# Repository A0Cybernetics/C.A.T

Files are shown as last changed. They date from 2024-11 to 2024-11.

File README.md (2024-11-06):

# A0 Cybernetics: C.A.T
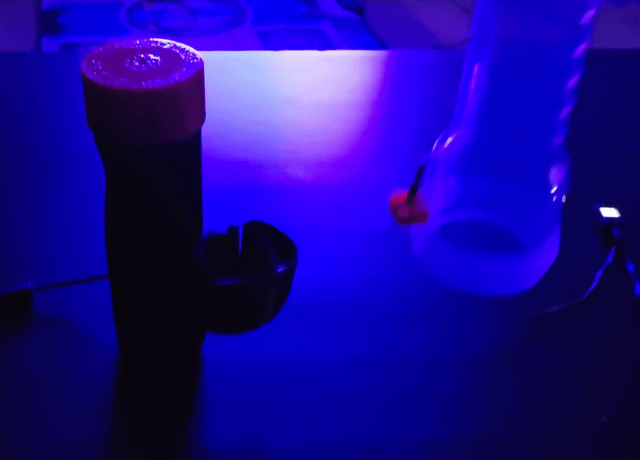
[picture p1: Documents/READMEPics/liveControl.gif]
liveControl
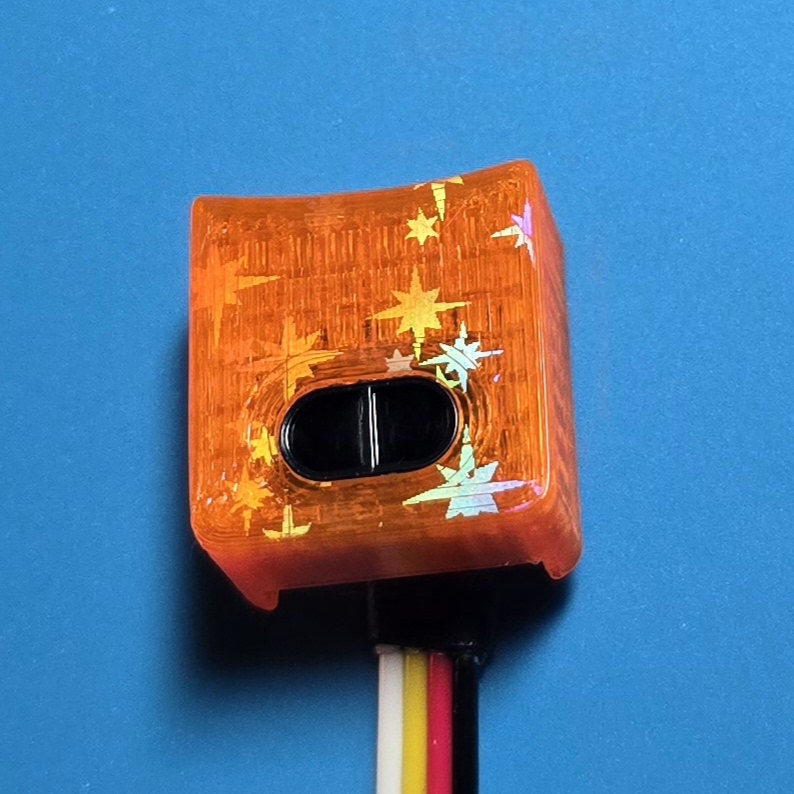
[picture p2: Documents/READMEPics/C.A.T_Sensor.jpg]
C.A.T_Sensor


An interactive adult entertainment device. It measures a targets distance from the sensor to control connected devices and interact with media.

- Free and open source. I do this because I like it <3

- Onboard TFT screen with customizable UI

- Control any computer UI slider based on the distance of a target from the sensor.

- Control most devices by using apps with sliders like Intiface Central, XToys, etc.

- Usable by any person.  Mount it on things with nano tape.  Point it at a target that moves farther and closer to the sensor.

- Read the [Build Guide](Documents/buildGuide.txt) for a parts list and fully detailed step-by-step instructions.

## License

[MIT](https://choosealicense.com/licenses/mit/)

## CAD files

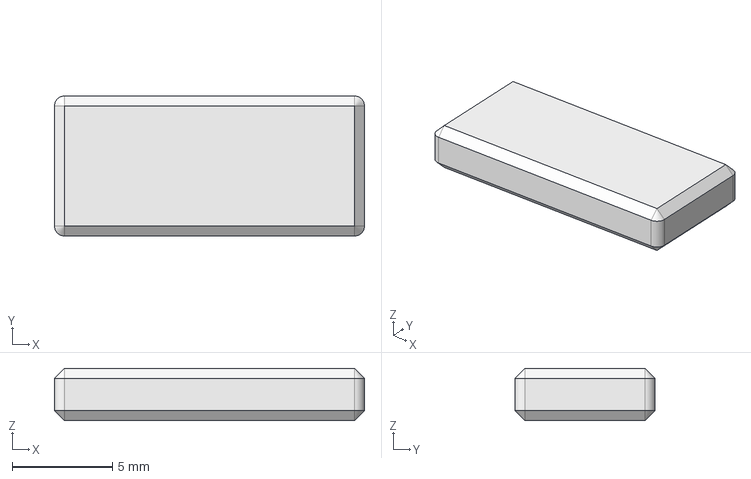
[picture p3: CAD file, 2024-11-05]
3DModels/C.A.T_Backplate-V1.0.FCStd
15.5 x 7.00 x 2.60 mm

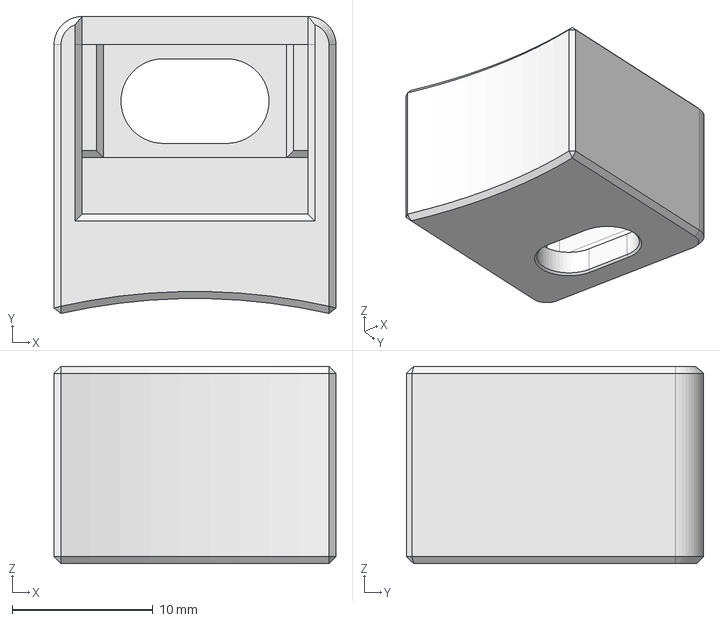
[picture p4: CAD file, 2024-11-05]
3DModels/C.A.T_Faceplate-V1.0.FCStd
20.0 x 21.1 x 14.0 mm

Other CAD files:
3DModels/C.A.T_Backplate-V1.0.stl
3DModels/C.A.T_Faceplate-V1.0.stl

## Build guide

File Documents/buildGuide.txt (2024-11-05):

---- C.A.T Build Guide ----
	*The pictures are in the C.A.T_InstructionPictures folder.

---- Parts List

1. LILYGO T-QT PRO (ESP32 S3FN8 VERSION) AND SHELL - Buy the shell to help protect the board, the pin and soldering options are your choice.
	https://www.lilygo.cc/products/t-qt-pro?variant=42568397324469

2. VL53L1X SENSOR BREAKOUT BOARD WITH COVER GLASS. One that looks like this picture (pic VL53L1X).  You can find them on Amazon, AliExpress, etc. for around $5.

3. Grove or QWIIC Cable - I recommend a long Grove Cable.  I have tested cabled up to 2 meters. 
	- The T-QT has a QWIIC Connector so you will need a Grove to QWIIC hub or another type of connector.  I plan to port this project to a board with a Grove port in the future.
	https://shop.m5stack.com/products/4pin-buckled-grove-cable?variant=32050977833050

4. 3D PRINTED C.A.T FACEPLAE - The C.A.T Backplate is optional and only recommended to improve the appearance of an unsealed hot glue build.

5. Electronic Grade RTV Silicone like ASI 388, or hot glue.  Use small dabs of hot glue to secure everything together if you want to be able to disassemble the C.A.T.  For a better device use silicone to seal the seam between the cover glass and case and to completely encapsulate the circuit board in the back.
	The C.A.T can be made extremely water resistant if you employ proper fabrication techniques.

---- C.A.T Assembly

1. Cut the screw hole sections off of the sides of the sensor breakout board. (pic assembly1)

2. Clean the sensor board and the inside of the cover glass.

3. Install the cover glass over the sensor.

4. Trim any edges of the cover glass that extend over the edge of the sensor board.  Make the whole board assembly rectangular. (pic assembly2)

5. Clean the sensor board assembly to prepare it for soldering.

6. Cut off one end of a QWIIC or Grove cable and solder the wires to the sensor board with the wire extending from the side opposite the cover glass.
	- Grove - Black to GND, Red to Volt, Yellow to SDA, White to SCL
	- QWIIC - Black to GND, Red to Volt, Blue to SDA, Yellow to SCL
	
7. With flush cutters, snip off the extra wire and solder sticking out of the board to make it flatter so that it can fit into the case. (pic assembly3)
	*optional - Add rings of heat shrink tubing to prevent the cable from splitting.

8. Clean the board and install it into the C.A.T Faceplate.

9. Use Silicone sealant or hot glue to fuse the sensor and faceplate. (pic assembly4)

---- Flashing Firmware

	1. Download Flash Download Tools from ESPRESSIF @ 	https://www.espressif.com/en/support/download/other-tools
	2. Run program
	3. Select ChipType: ESP32-S3; WorkMode: Develop; LoadMode: UART; OK (pic firmware1)
	4. Select firmware @ 0x0 (pic firmware2)
	5. Connect board to computer, select COM port for the board
	6. Press Start
	7. When download panel shows FINISH (pic firmware3), press reset on the board to 	verify download, disconnect board and close program

---- USING THE C.A.T MOUSE MODE ON WINDOWS

1.  Search for Mouse Settings in the start menu search bar.

2.  In the Mouse settings.  Go near the bottom of the Mouse Settings and click on Additional Mouse Settings.  This will open the Mouse Properties window.

3.  Click on the Pointer Options tab an uncheck the Enhance Pointer Precision box. (pic mouseProperties)
	- This will make the mouse properly when using the C.A.T.  This makes the mouse return to the same starting point.  If you don't to this
	the mouse will drift.

4.  The C.A.T acts like a computer mouse that moves when a target moves closer or farther from the sensor.
	Point the sensor at a target.  When the target moves within the sensing range the mouse will move on the screen.

5.  With your normal mouse, move the mouse cursor to the spot that you want to grab with the TQT.

6.  Toggle the Mouse : Released / grabbed option to grab a UI slider.

7.  To change the direction the mouse moves toggle the Invert Output option.

8.  To change the axis the mouse moves in toggle the Mouse Axis option.

*.  If you want to use your regular mouse just start using your regular mouse again.

*.  If you have any problems try: Press the T-QT reset button to reset the controller.
	Verify that all cables are connected securely.
	Disconnect and reconnect the USB cable to the computer.

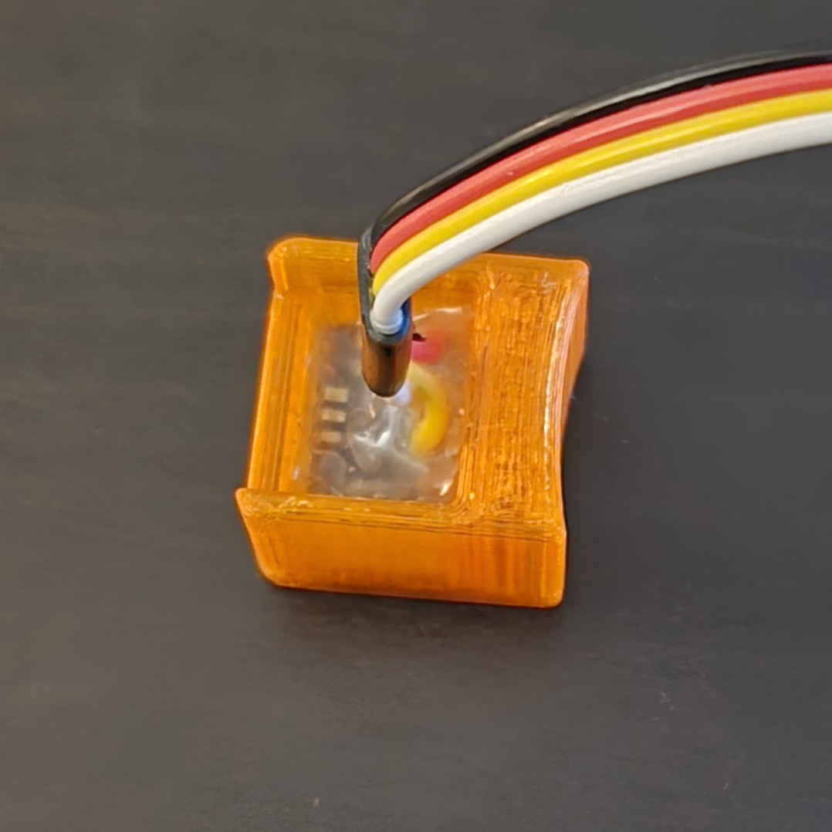
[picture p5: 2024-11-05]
Documents/buildGuidePictures/assembly4.jpg

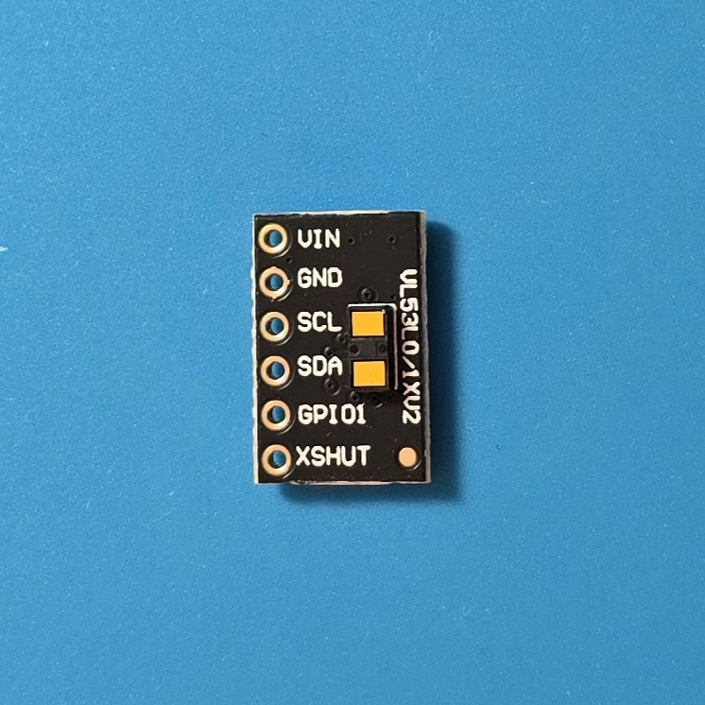
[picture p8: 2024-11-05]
Documents/buildGuidePictures/assembly1.jpg

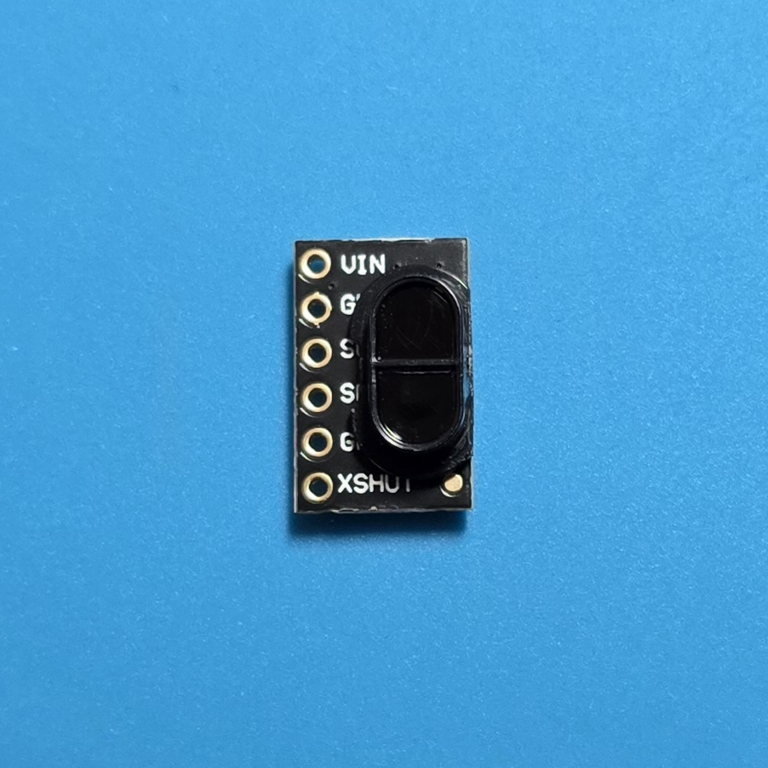
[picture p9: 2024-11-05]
Documents/buildGuidePictures/assembly2.jpg

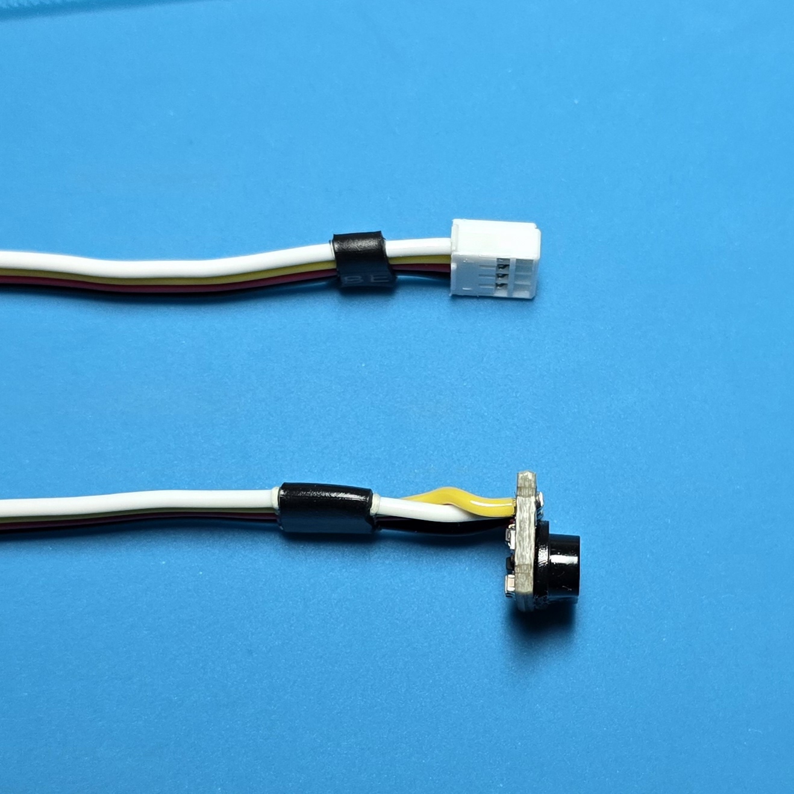
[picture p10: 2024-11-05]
Documents/buildGuidePictures/assembly3.jpg

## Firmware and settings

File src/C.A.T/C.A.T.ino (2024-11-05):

#include <Arduino.h>
#include <Wire.h>

// Prefrences library for saving data to onboard flash from espressif
// https://github.com/espressif/arduino-esp32
// https://docs.espressif.com/projects/arduino-esp32/en/latest/api/preferences.html
#include <Preferences.h>
Preferences preferences;

// USB Mouse - from espressif board library
#include "USB.h"
#include "USBHIDMouse.h"
USBHIDMouse Mouse;

// Screen
// *Have to modify User_Setup_Select.h to select board. Uncomment //#include <User_Setups/Setup211_LilyGo_T_QT_Pro_S3.h> and comment out //#include <User_Setup.h>
// *Also: Rollback esp32 Boards Manager to 2.0.14 - Screen wouldnt work on newer releases
// https://github.com/Bodmer/TFT_eSPI
#include <TFT_eSPI.h>
TFT_eSPI tft = TFT_eSPI();

// VL53L1X Sensor lib
// https://github.com/pololu/vl53l1x-arduino
#include <VL53L1X.h>
VL53L1X sensorV1X;

// 1Euro Filter for VL53L1X data
// https://github.com/casiez/OneEuroFilterArduino
#include "1euroFilter.h"
static OneEuroFilter distanceFilter;

// Board Pin Definitions
#define PIN_BUTTON_1 47 // KEY onboard button
#define PIN_BUTTON_2 0  // IO0 onboard button
#define PIN_BAT_VOLT 4  // Battery voltage analog; analogRead(PIN_BAT_VOLT)
#define PIN_LCD_BL 10 // Screen backlight pin, screen backlight takes 20mA

// QWIIC pin defs
#define PIN_QWIIC_SDA 43
#define PIN_QWIIC_SCL 44

//////////////////////////////////////////
/////////     Main Functions     /////////
//////////////////////////////////////////

 void setup() {
  Serial.begin(115200);     //9600  115200
    // Setup onboard buttons
  pinMode(PIN_BUTTON_1, INPUT_PULLUP);
  pinMode(PIN_BUTTON_2, INPUT_PULLUP);
    // load prefrences and initialize pref vars
  loadPreferences();
    // Setup I2C
  wireSetup();
    // Setup screen
  tftSetup();
    // Setup ToF Sensor
  VL53L1XSetup();
    // Select starting menu page
  mainMenuSelect();
    // Initialize mouse control:
  Mouse.begin();
  USB.begin();
}

void loop() {
  menuFn();
}

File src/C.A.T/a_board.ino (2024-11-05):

////////// Battery //////////
uint batteryVoltage = 0;
const uint16_t batteryVoltageUpdateInterval = 10000;
unsigned long batteryVoltageNextUpdateTime = 0;

////////// ONBOARD BUTTONS //////////
  //INPUT_PULLUP => 1 HIGH when not pressed, 0 LOW when pressed
bool but1State = 1;
bool but1StateLast = 1;
bool but2State = 1;
bool but2StateLast = 1;

unsigned long currentTime = 0;  //global var to store millis() micros()
const uint8_t butDebounceDelay = 59;
const uint16_t butHoldDelay = 500;
unsigned long but1NextDebounceTime = 0;
unsigned long but2NextDebounceTime = 0;
unsigned long but1NextHoldTime = 0;
unsigned long but2NextHoldTime = 0;
bool but1HoldFlag = 0;
bool but2HoldFlag = 0;

////////// TFT, Colors & Font //////////
struct color {
  String name;
  uint8_t r;
  uint8_t g;
  uint8_t b;
};

  // array 140 HTML colors color structs
const uint8_t colorArrSize = 140;
color colorArr[colorArrSize] = {	
	{"Alice Blue", 0xF0, 0xF8, 0xFF},
	{"Antique White", 0xFA, 0xEB, 0xD7},
	{"Aqua", 0x00, 0xFF, 0xFF},
	{"Aquamarine", 0x7F, 0xFF, 0xD4},
	{"Azure", 0xF0, 0xFF, 0xFF},
	{"Beige", 0xF5, 0xF5, 0xDC},
	{"Bisque", 0xFF, 0xE4, 0xC4},
	{"Black", 0x00, 0x00, 0x00},
	{"Blanched Almond", 0xFF, 0xEB, 0xCD},
	{"Blue", 0x00, 0x00, 0xFF},
	{"Blue Violet", 0x8A, 0x2B, 0xE2},
	{"Brown", 0xA5, 0x2A, 0x2A},
	{"Burly Wood", 0xDE, 0xB8, 0x87},
	{"Cadet Blue", 0x5F, 0x9E, 0xA0},
	{"Chartreuse", 0x7F, 0xFF, 0x00},
	{"Chocolate", 0xD2, 0x69, 0x1E},
	{"Coral", 0xFF, 0x7F, 0x50},
	{"Cornflower Blue", 0x64, 0x95, 0xED},
	{"Cornsilk", 0xFF, 0xF8, 0xDC},
	{"Crimson", 0xDC, 0x14, 0x3C},
	{"Cyan", 0x00, 0xFF, 0xFF},
	{"Dark Blue", 0x00, 0x00, 0x8B},
	{"Dark Cyan", 0x00, 0x8B, 0x8B},
	{"Dark Golden Rod", 0xB8, 0x86, 0x0B},
	{"Dark Gray", 0xA9, 0xA9, 0xA9},
	{"Dark Green", 0x00, 0x64, 0x00},
	{"Dark Khaki", 0xBD, 0xB7, 0x6B},
	{"Dark Magenta", 0x8B, 0x00, 0x8B},
	{"Dark Olive Green", 0x55, 0x6B, 0x2F},
	{"Dark Orange", 0xFF, 0x8C, 0x00},
	{"Dark Orchid", 0x99, 0x32, 0xCC},
	{"Dark Red", 0x8B, 0x00, 0x00},
	{"Dark Salmon", 0xE9, 0x96, 0x7A},
	{"Dark Sea Green", 0x8F, 0xBC, 0x8F},
	{"Dark Slate Blue", 0x48, 0x3D, 0x8B},
	{"Dark Sate Gray", 0x2F, 0x4F, 0x4F},
	{"Dark Turquoise", 0x00, 0xCE, 0xD1},
	{"Dark Violet", 0x94, 0x00, 0xD3},
	{"Deep Pink", 0xFF, 0x14, 0x93},
	{"Deep Sky Blue", 0x00, 0xBF, 0xFF},
	{"Dim Gray", 0x69, 0x69, 0x69},
	{"Dodger Blue", 0x1E, 0x90, 0xFF},
	{"Fire Brick", 0xB2, 0x22, 0x22},
	{"Floral White", 0xFF, 0xFA, 0xF0},
	{"Forest Green", 0x22, 0x8B, 0x22},
	{"Fuchsia", 0xFF, 0x00, 0xFF},
	{"Gainsboro", 0xDC, 0xDC, 0xDC},
	{"Ghost White", 0xF8, 0xF8, 0xFF},
	{"Gold", 0xFF, 0xD7, 0x00},
	{"Golden Rod", 0xDA, 0xA5, 0x20},
	{"Gray", 0x80, 0x80, 0x80},
	{"Green", 0x00, 0x80, 0x00},
	{"Green Yellow", 0xAD, 0xFF, 0x2F},
	{"Honey Dew", 0xF0, 0xFF, 0xF0},
	{"Hot Pink", 0xFF, 0x69, 0xB4},
	{"Indian Red", 0xCD, 0x5C, 0x5C},
	{"Indigo", 0x4B, 0x00, 0x82},
	{"Ivory", 0xFF, 0xFF, 0xF0},
	{"Khaki", 0xF0, 0xE6, 0x8C},
	{"Lavender", 0xE6, 0xE6, 0xFA},
	{"Lavender Blush", 0xFF, 0xF0, 0xF5},
	{"Lawn Green", 0x7C, 0xFC, 0x00},
	{"Lemon Chiffon", 0xFF, 0xFA, 0xCD},
	{"Light Blue", 0xAD, 0xD8, 0xE6},
	{"Light Coral", 0xF0, 0x80, 0x80},
	{"Light Cyan", 0xE0, 0xFF, 0xFF},
	{"Light Golden Rod Yellow", 0xFA, 0xFA, 0xD2},
	{"Light Gray", 0xD3, 0xD3, 0xD3},
	{"Light Green", 0x90, 0xEE, 0x90},
	{"Light Pink", 0xFF, 0xB6, 0xC1},
	{"Light Salmon", 0xFF, 0xA0, 0x7A},
	{"Light Sea Green", 0x20, 0xB2, 0xAA},
	{"Light Sky Blue", 0x87, 0xCE, 0xFA},
	{"Light Slate Gray", 0x77, 0x88, 0x99},
	{"Light Steel Blue", 0xB0, 0xC4, 0xDE},
	{"Light Yellow", 0xFF, 0xFF, 0xE0},
	{"Lime", 0x00, 0xFF, 0x00},
	{"Lime Green", 0x32, 0xCD, 0x32},
	{"Linen", 0xFA, 0xF0, 0xE6},
	{"Magenta", 0xFF, 0x00, 0xFF},
	{"Maroon", 0x80, 0x00, 0x00},
	{"Medium Aqua Marine", 0x66, 0xCD, 0xAA},
	{"Medium Blue", 0x00, 0x00, 0xCD},
	{"Medium Orchid", 0xBA, 0x55, 0xD3},
	{"Medium Purple", 0x93, 0x70, 0xDB},
	{"Medium Sea Green", 0x3C, 0xB3, 0x71},
	{"Medium Slate Blue", 0x7B, 0x68, 0xEE},
	{"Medium Spring Green", 0x00, 0xFA, 0x9A},
	{"Medium Turquoise", 0x48, 0xD1, 0xCC},
	{"Medium Violet Red", 0xC7, 0x15, 0x85},
	{"Midnight Blue", 0x19, 0x19, 0x70},
	{"Mint Cream", 0xF5, 0xFF, 0xFA},
	{"Misty Rose", 0xFF, 0xE4, 0xE1},
	{"Moccasin", 0xFF, 0xE4, 0xB5},
	{"Navajo White", 0xFF, 0xDE, 0xAD},
	{"Navy", 0x00, 0x00, 0x80},
	{"Old Lace", 0xFD, 0xF5, 0xE6},
	{"Olive", 0x80, 0x80, 0x00},
	{"Olive Drab", 0x6B, 0x8E, 0x23},
	{"Orange", 0xFF, 0xA5, 0x00},
	{"Orange Red", 0xFF, 0x45, 0x00},
	{"Orchid", 0xDA, 0x70, 0xD6},
	{"Pale Golden Rod", 0xEE, 0xE8, 0xAA},
	{"Pale Green", 0x98, 0xFB, 0x98},
	{"Pale Turquoise", 0xAF, 0xEE, 0xEE},
	{"Pale Violet Red", 0xDB, 0x70, 0x93},
	{"Papaya Whip", 0xFF, 0xEF, 0xD5},
	{"Peach Puff", 0xFF, 0xDA, 0xB9},
	{"Peru", 0xCD, 0x85, 0x3F},
	{"Pink", 0xFF, 0xC0, 0xCB},
	{"Plum", 0xDD, 0xA0, 0xDD},
	{"Powder Blue", 0xB0, 0xE0, 0xE6},
	{"Purple", 0x80, 0x00, 0x80},
	{"Red", 0xFF, 0x00, 0x00},
	{"Rosy Brown", 0xBC, 0x8F, 0x8F},
	{"Royal Blue", 0x41, 0x69, 0xE1},
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

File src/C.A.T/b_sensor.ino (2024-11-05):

//////////////////////////////////////////
//////   VL53L1X TOF SENSOR Vars   ///////
//////////////////////////////////////////
//unsigned long lastReadingTime = 0;        // For timing testing of functions
bool newDistanceFlag = 0;                 // Indicate if there is a new distance reading
uint16_t distance = 0;                    // Store distance reading of sensor
uint16_t distanceFiltered = 0;            // Store filtered distance reading

unsigned long autoRangeTime = 10000;      // Time that auto range function runs for
uint16_t rangeMax = 200;                  // Upper limit of used sensor distance range, set in autoRange
uint16_t rangeMin = 100;                  // Lower limit of used sensor distance range, set in autoRange
uint16_t strokeLength = 100;              // Length of stroke, strokeLength = rangeMax-rangeMin , set in autoRange
bool invertOutput = 0;                    // Invert mapping of distance to output variable, if 1: increase distance = decrease output
int16_t mouseMinPx = 0;                   // -127 (-128) max without fancy Mouse.move Maximum Value -32768
int16_t mouseMaxPx = 125;                 // 127 max (125 for 5 px increment) without fancy Mouse.move fn // Maximum Value 32767
int16_t mouseMaxPxLimit = 250;            // 127 max (125 for 5 px increment) without fancy Mouse.move fn // Maximum Value 32767
int16_t mousePxRaw = 0;                   // Raw mapping value of distance to position range in pixels
int16_t mousePxFiltered = 0;              // Filtered position value
int8_t mouseAxis = 0;           // Set axis of mouse movement 0 = x axis, 1 = y axis
int16_t mousePxLast = 0;       // Position of mouse after the last Mouse.move()
int16_t mousePxChange = 0;     // Mouse uses int8_t value for moving mouse, keep movement range per Mouse.move() : -128 to 127 px; will limit to abs 127 per move (limited by Mouse.move number type int8_t)
bool mouseGrab = 0;             // Press or release mouse button to grab; 1 = mouse button pressed, 0 = mouse button released
bool mousePaused = 0;           // Pause moving mouse 0 = mouse button released, 1 = mouse paused

// 1 Euro Filter vars
float FREQUENCY = 50.0;       // [Hz]
float MINCUTOFF = 3.4E+38;    // [Hz] needs to be tuned according to your application
float BETA = 3.4E+38;         // needs to be tuned according to your application
unsigned long filterStartTime = 0;


//////////////////////////////////////////
//////      VL53L1X TOF SENSOR     ///////
//////////////////////////////////////////
void VL53L1XSetup() {
   // Start VL53L1X = sensorV1X
  sensorV1X.setTimeout(500);
  if (!sensorV1X.init()) {
    while (1);
  }

  // Use long distance mode and allow up to 50000 us (50 ms) for a measurement.
  // You can change these settings to adjust the performance of the sensor, but
  // the minimum timing budget is 20 ms for short distance mode and 33 ms for
  // medium and long distance modes. See the VL53L1X datasheet for more

  //************** This library sets up the sensor to use the LOWPOWER_AUTONOMOUS preset mode, and in that mode, John Kvam recommends using an 
  //inter-measurement period (the value passed to startContinuous() in our library) of at least 5 ms longer than the timing budget.
  // So using startContinuous(25) seems to work and consistently give me readings every 25 ms. Or if you really need readings
  // every 20 ms, it also seems to work if I do setMeasurementTimingBudget(15000) and startContinuous(20), even though 15 ms is below the supposed minimum timing budget of 20 ms .

  // information on range and timing limits.
  sensorV1X.setDistanceMode(VL53L1X::Short);
  sensorV1X.setMeasurementTimingBudget(15000);   //2000
  //sensorV1X.setDistanceMode(VL53L1X::Medium);
  //sensorV1X.setMeasurementTimingBudget(33000);
  //sensorV1X.setDistanceMode(VL53L1X::Long);
  //sensor.V1XsetMeasurementTimingBudget(50000);

  //sensorV1X.setROISize(16, 16);  // Default
  //sensorV1X.setROISize(4, 4);    // Minimum

  // Start continuous readings at a rate of one measurement every 50 ms (the
  // inter-measurement period). This period should be at least as long as the
  // timing budget.
  sensorV1X.startContinuous(20);    //20
  //sensorV1X.startContinuous(33);
  //sensorV1X.startContinuous(50); 

  //sensorV1X.stopContinuous();
}

// Check distance and set new distance flag if there is a new distance reading
void checkDistance() {
  if (sensorV1X.dataReady()) {            // if new measurement for the taking!
    sensorV1X.read();
    if (sensorV1X.ranging_data.range_status == 0) {   // if a valid distance reading
      distance = sensorV1X.ranging_data.range_mm;
      newDistanceFlag = 1;
    }
    else {
      newDistanceFlag = 0;
    }
  }
  else {
    newDistanceFlag = 0;
  }
}

//////////////////////////////////////////
//////      1 Euro Filter FNS      ///////
//////////////////////////////////////////

void setupDistanceFilter () {
    distanceFilter.begin(FREQUENCY, MINCUTOFF, BETA);
    filterStartTime = micros();
}

// Apply 1 Euro Filter to raw distance reading to set distanceFiltered
int16_t filterDistance() {
  distanceFiltered = distanceFilter.filter(distance);
  return distanceFiltered;
}
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
